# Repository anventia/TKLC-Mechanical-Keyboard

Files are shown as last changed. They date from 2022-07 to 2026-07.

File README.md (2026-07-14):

# Tenkeyless-Compact
A Tenkeyless (TKL) Mechanical Keyboard, but more compact.
- PCB custom-made in KiCAD
- Support for:
  - Standard Cherry-style hotswappable switches
  - Gateron Low Profile hotswappable switches + Kailh Choc LP Stabilizers
- 3D printed plate + case 
 




[More images here](https://photos.anv3d.net/share/XmMfmQBNBfAzoucF3x74RvwrajWIMN9iaQ0uHyBkrugpA7lCPas15zOcdVT3Yqxft6Q)

Layout (from [Keyboard Layout Editor](http://www.keyboard-layout-editor.com/))
tkl-compact (2)

Libraries used: 
- https://github.com/sszczep/kicad-libraries
- https://github.com/Kriechi/kicad-library-WeAct-RP2040-Pico

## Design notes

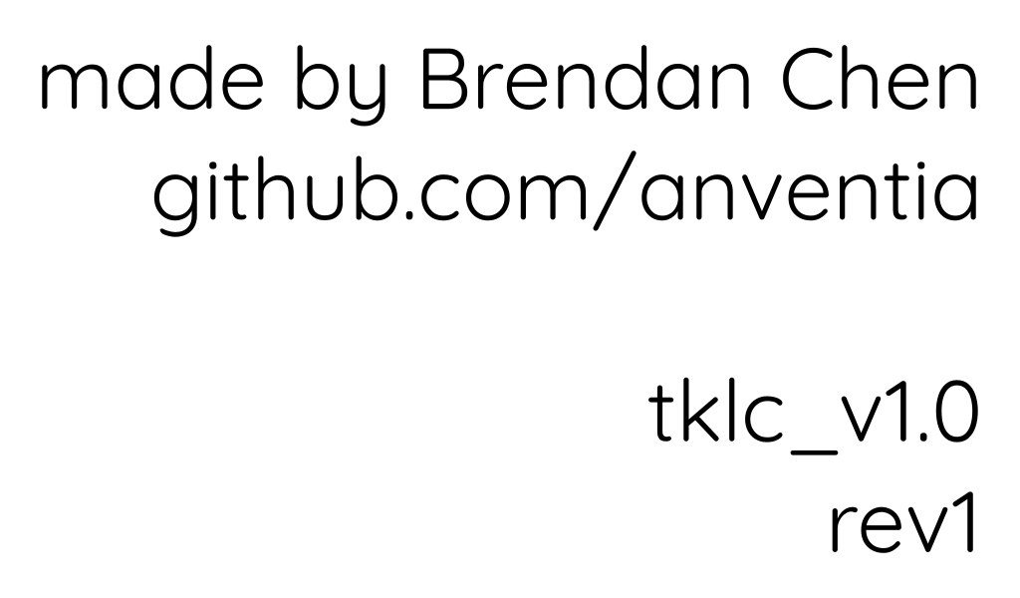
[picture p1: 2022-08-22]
TKLC_v1/resources/text.png

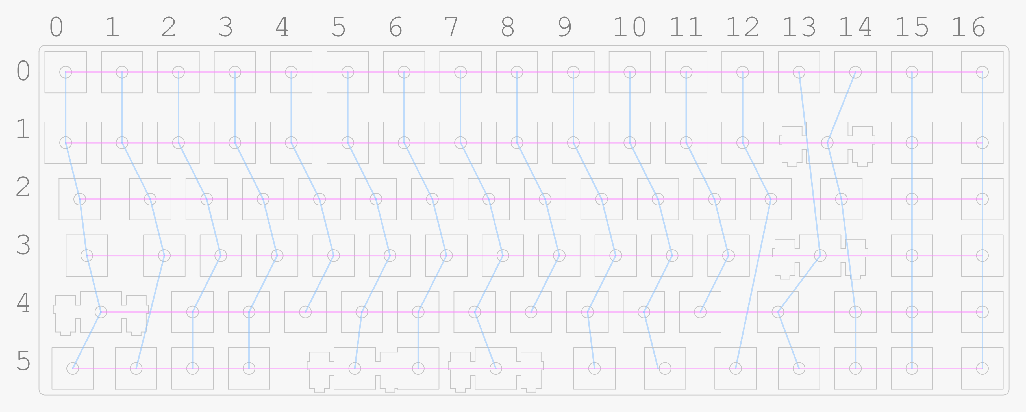
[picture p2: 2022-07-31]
TKLC_v1/resources/rows_columns_reference.png

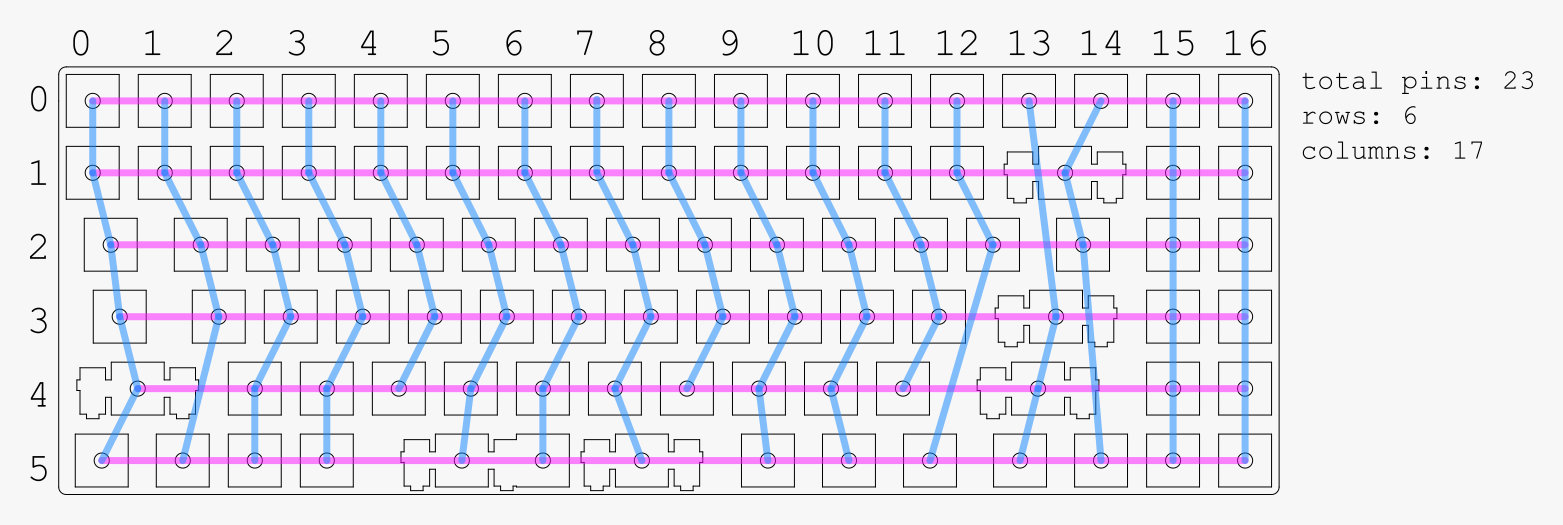
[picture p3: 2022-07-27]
TKLC_v1/resources/rows_columns.png

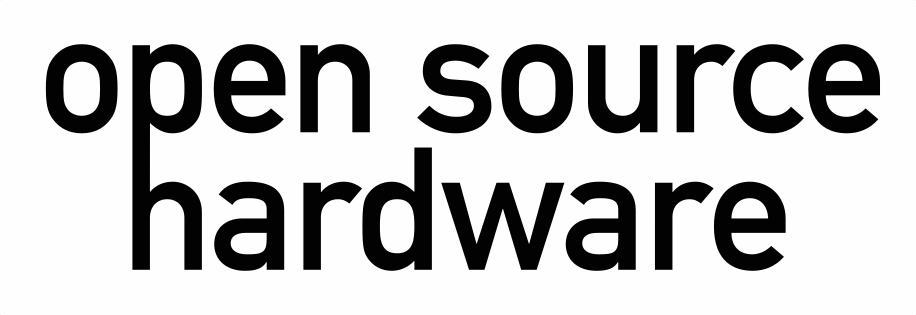
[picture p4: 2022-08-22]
TKLC_v1/resources/oshw_text.png

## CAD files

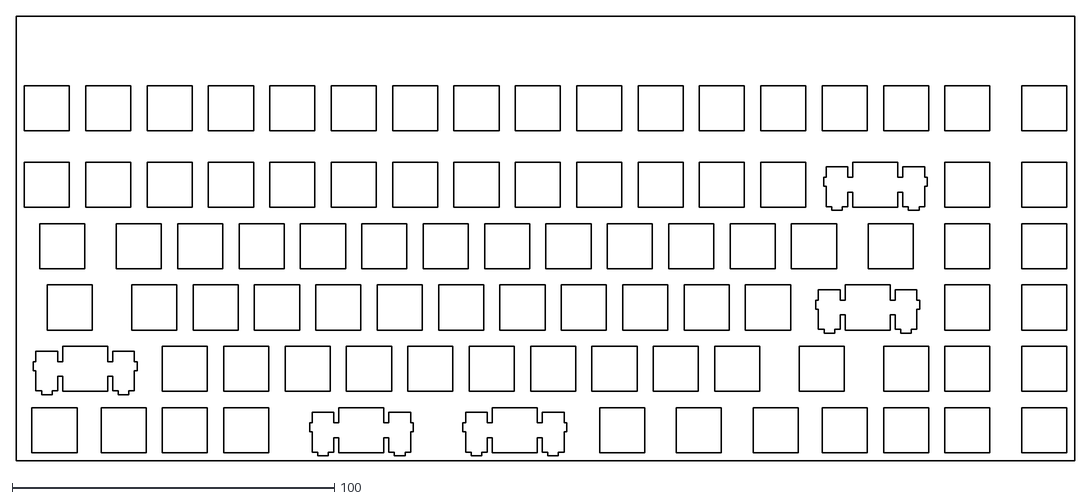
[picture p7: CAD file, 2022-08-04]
TKLC_v1/resources/layout-updated.dxf
328.6 x 138.1

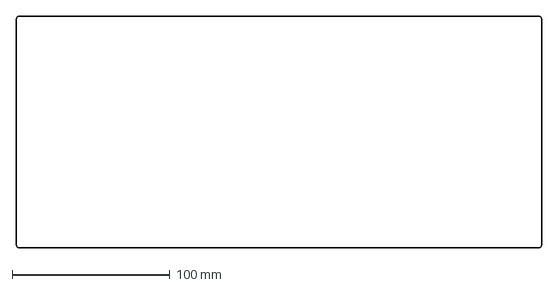
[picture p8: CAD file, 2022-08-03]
TKLC_v1/resources/pcb_frame.dxf
332.6 x 146.9 mm

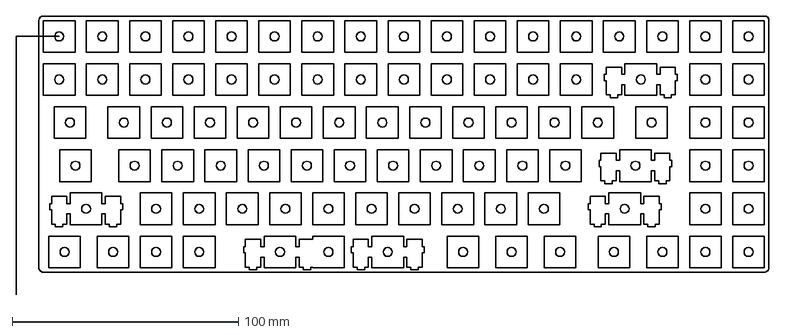
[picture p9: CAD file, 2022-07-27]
TKLC_v1/resources/switch_alignment.dxf
332.9 x 123.3 mm

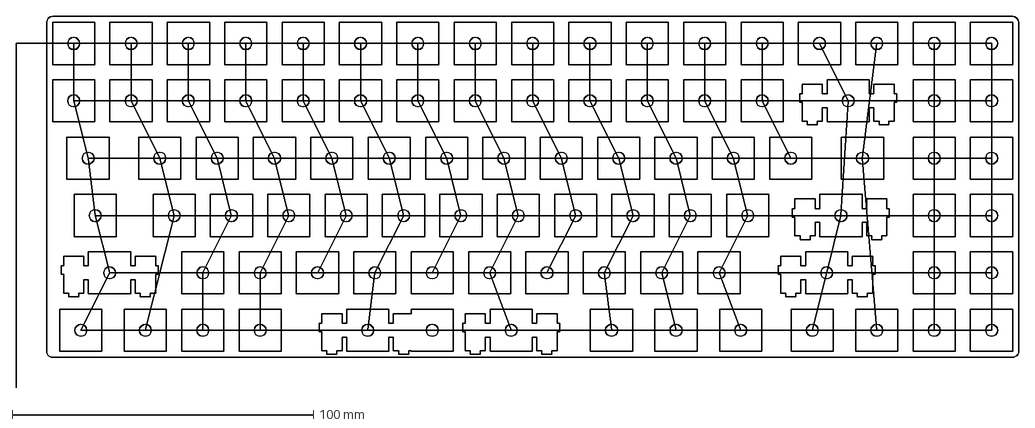
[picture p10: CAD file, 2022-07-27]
TKLC_v1/resources/rows_columns.dxf
332.9 x 123.3 mm

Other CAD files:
TKLC_v1/resources/test.dxf

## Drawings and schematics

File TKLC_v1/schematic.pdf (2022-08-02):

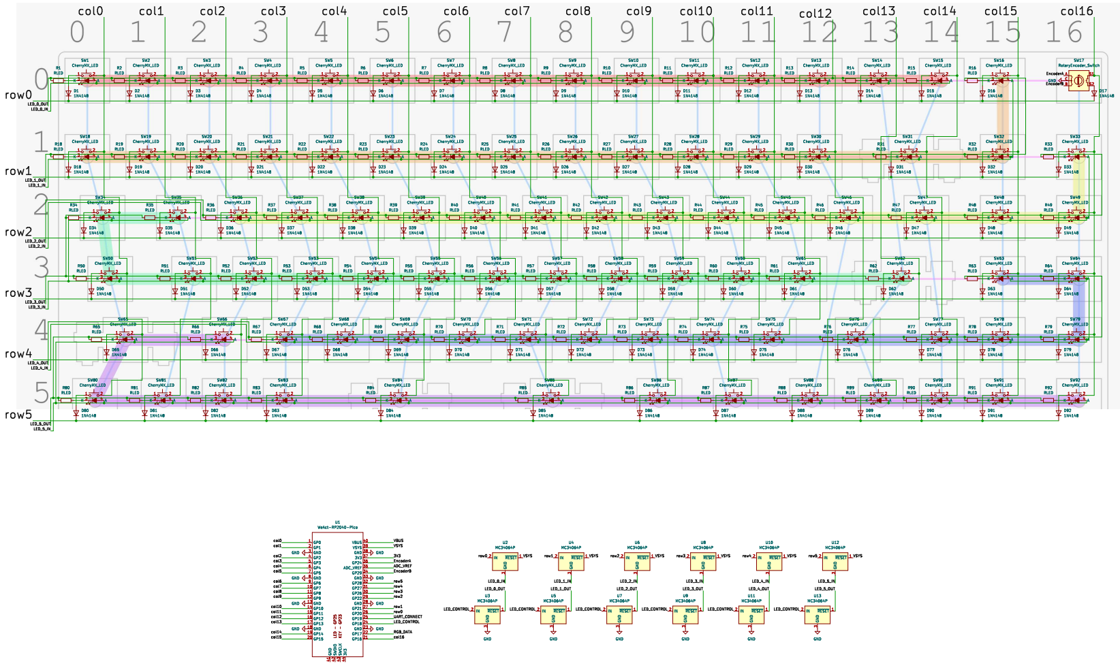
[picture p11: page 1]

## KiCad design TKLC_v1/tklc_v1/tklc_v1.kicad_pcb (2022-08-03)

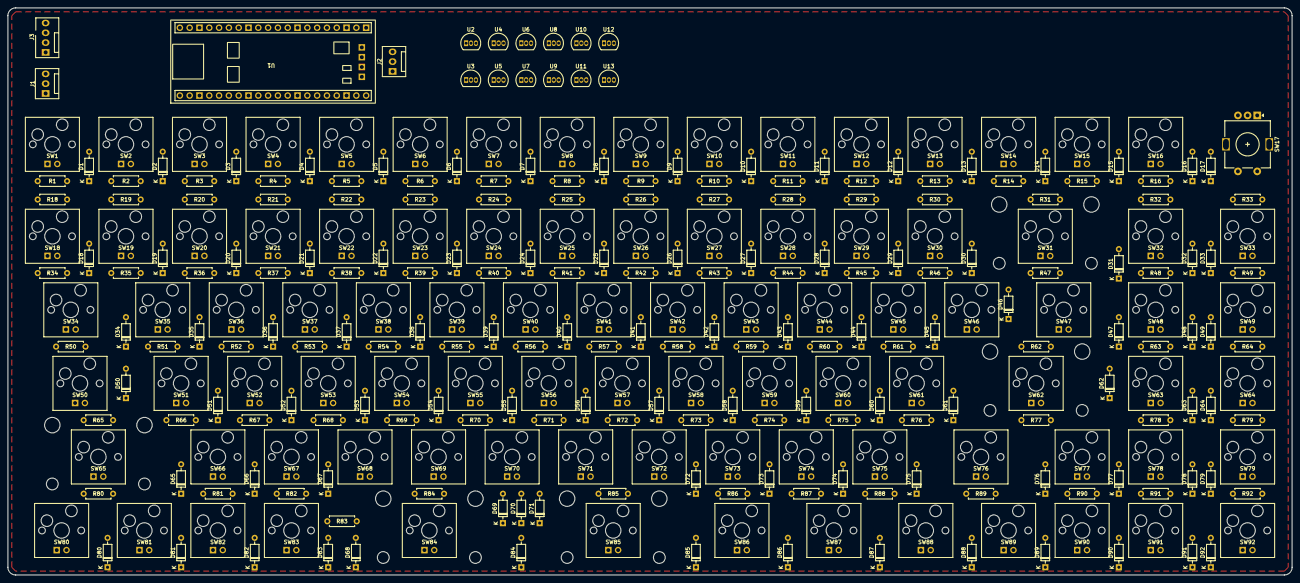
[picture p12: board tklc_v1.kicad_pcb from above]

Board: 2 copper layers, 332.6 x 146.9 mm, 291 parts (0 on the bottom side), 227 nets, no tracks yet.

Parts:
D1, D2, D3, D4, D5, D6, D7, D8, D9, D10, D11, D12, D13, D14, D15, D16, D17, D18, D19, D20, D21, D22, D23, D24, D25, D26, D27, D28, D29, D30, D31, D32, D33, D34, D35, D36, D37, D38, D39, D40, D41, D42, D43, D44, D45, D46, D47, D48, D49, D50, D51, D52, D53, D54, D55, D56, D57, D58, D59, D60, D61, D62, D63, D64, D65, D66, D67, D68, D69, D70, D71, D72, D73, D74, D75, D76, D77, D78, D79, D80, D81, D82, D83, D84, D85, D86, D87, D88, D89, D90, D91, D92: 1N4148; D_DO-35_SOD27_P7.62mm_Horizontal
J1: UART breakout for extension board; FanPinHeader_1x03_P2.54mm_Vertical
J2: RGB Strip breakout; FanPinHeader_1x03_P2.54mm_Vertical
J3: Encoder breakout; FanPinHeader_1x04_P2.54mm_Vertical
R1, R2, R3, R4, R5, R6, R7, R8, R9, R10, R11, R12, R13, R14, R15, R16, R18, R19, R20, R21, R22, R23, R24, R25, R26, R27, R28, R29, R30, R31, R32, R33, R34, R35, R36, R37, R38, R39, R40, R41, R42, R43, R44, R45, R46, R47, R48, R49, R50, R51, R52, R53, R54, R55, R56, R57, R58, R59, R60, R61, R62, R63, R64, R65, R66, R67, R68, R69, R70, R71, R72, R73, R74, R75, R76, R77, R78, R79, R80, R81, R82, R83, R84, R85, R86, R87, R88, R89, R90, R91, R92: RLED; R_Axial_DIN0207_L6.3mEDIT_m_D2.5mm_P7.62mm_Horizontal
SW1, SW2, SW3, SW4, SW5, SW6, SW7, SW8, SW9, SW10, SW11, SW12, SW13, SW14, SW15, SW16, SW18, SW19, SW20, SW21, SW22, SW23, SW24, SW25, SW26, SW27, SW28, SW29, SW30, SW32, SW33, SW35, SW36, SW37, SW38, SW39, SW40, SW41, SW42, SW43, SW44, SW45, SW46, SW48, SW49, SW51, SW52, SW53, SW54, SW55, SW56, SW57, SW58, SW59, SW60, SW61, SW63, SW64, SW66, SW67, SW68, SW69, SW70, SW71, SW72, SW73, SW74, SW75, SW77, SW78, SW79, SW81, SW82, SW83, SW89, SW90, SW91, SW92: CherryMX_LED; CherryMX_1.00u_PCB_KailhSocket_LED
SW17: RotaryEncoder_Switch; EDIT_RotaryEncoder_Alps_EC11E-Switch_Vertical_H20mm
SW31: CherryMX_LED; CherryMX_2.00u_PCB_KailhSocket_StabWireTop_LED
SW34, SW47: CherryMX_LED; CherryMX_1.50u_PCB_KailhSocket_LED
SW50, SW76: CherryMX_LED; CherryMX_1.75u_PCB_KailhSocket_LED
SW62, SW65, SW85: CherryMX_LED; CherryMX_2.25u_PCB_KailhSocket_StabWireTop_LED
SW80, SW86, SW87, SW88: CherryMX_LED; CherryMX_1.25u_PCB_KailhSocket_LED
SW84: CherryMX_LED; CherryMX_2.75u_PCB_KailhSocket_StabWireTop_LED
U1: WeAct-RP2040-Pico
U2, U3, U4, U5, U6, U7, U8, U9, U10, U11, U12, U13: MC34064P; TO-92L_Inline

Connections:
/3V3: J1.3, U1.37 (3V3)
/EncoderA: J3.1, SW17.A, U1.36 (GP24)
/EncoderB: J3.2, SW17.B, U1.34 (GP29)
/LED_0_IN: SW1.4 (A), SW2.4 (A), SW3.4 (A), SW4.4 (A), SW5.4 (A), SW6.4 (A), SW7.4 (A), SW8.4 (A), SW9.4 (A), SW10.4 (A), SW11.4 (A), SW12.4 (A), SW13.4 (A), SW14.4 (A), SW15.4 (A), U2.3 (GND)
/LED_0_OUT: R1.1, R2.1, R3.1, R4.1, R5.1, R6.1, R7.1, R8.1, R9.1, R10.1, R11.1, R12.1, R13.1, R14.1, R15.1, U1.16 (GP12), U3.1 (~RESET)
/LED_1_IN: SW16.4 (A), SW18.4 (A), SW19.4 (A), SW20.4 (A), SW21.4 (A), SW22.4 (A), SW23.4 (A), SW24.4 (A), SW25.4 (A), SW26.4 (A), SW27.4 (A), SW28.4 (A), SW29.4 (A), SW30.4 (A), SW31.4 (A), SW32.4 (A), U4.3 (GND)
/LED_1_OUT: R16.1, R18.1, R19.1, R20.1, R21.1, R22.1, R23.1, R24.1, R25.1, R26.1, R27.1, R28.1, R29.1, R30.1, R31.1, R32.1, U5.1 (~RESET)
/LED_2_IN: SW33.4 (A), SW36.4 (A), SW37.4 (A), SW38.4 (A), SW39.4 (A), SW40.4 (A), SW41.4 (A), SW42.4 (A), SW43.4 (A), SW44.4 (A), SW45.4 (A), SW46.4 (A), SW47.4 (A), SW48.4 (A), SW49.4 (A), U6.3 (GND)
/LED_2_OUT: R33.1, R36.1, R37.1, R38.1, R39.1, R40.1, R41.1, R42.1, R43.1, R44.1, R45.1, R46.1, R47.1, R48.1, R49.1, U7.1 (~RESET)
/LED_3_IN: SW34.4 (A), SW35.4 (A), SW50.4 (A), SW51.4 (A), SW52.4 (A), SW53.4 (A), SW54.4 (A), SW55.4 (A), SW56.4 (A), SW57.4 (A), SW58.4 (A), SW59.4 (A), SW60.4 (A), SW61.4 (A), SW62.4 (A), U8.3 (GND)
/LED_3_OUT: R34.1, R35.1, R50.1, R51.1, R52.1, R53.1, R54.1, R55.1, R56.1, R57.1, R58.1, R59.1, R60.1, R61.1, R62.1, U9.1 (~RESET)
/LED_4_IN: SW63.4 (A), SW64.4 (A), SW67.4 (A), SW68.4 (A), SW69.4 (A), SW70.4 (A), SW71.4 (A), SW72.4 (A), SW73.4 (A), SW74.4 (A), SW75.4 (A), SW76.4 (A), SW77.4 (A), SW78.4 (A), SW79.4 (A), U10.3 (GND)
/LED_4_OUT: R63.1, R64.1, R67.1, R68.1, R69.1, R70.1, R71.1, R72.1, R73.1, R74.1, R75.1, R76.1, R77.1, R78.1, R79.1, U11.1 (~RESET)
/LED_5_IN: SW65.4 (A), SW66.4 (A), SW80.4 (A), SW81.4 (A), SW82.4 (A), SW83.4 (A), SW84.4 (A), SW85.4 (A), SW86.4 (A), SW87.4 (A), SW88.4 (A), SW89.4 (A), SW90.4 (A), SW91.4 (A), SW92.4 (A), U12.3 (GND)
/LED_5_OUT: R65.1, R66.1, R80.1, R81.1, R82.1, R83.1, R84.1, R85.1, R86.1, R87.1, R88.1, R89.1, R90.1, R91.1, R92.1, U13.1 (~RESET)
/LED_CONTROL: U1.24 (GP18), U3.2 (IN), U5.2 (IN), U7.2 (IN), U9.2 (IN), U11.2 (IN), U13.2 (IN)
/RGB_DATA: J2.3, U1.22 (GP17)
/UART_CONNECT: J1.2, U1.25 (GP19)
/VBUS: J2.2, U1.40 (VBUS)
/VSYS: U1.39 (VSYS), U2.1 (~RESET), U4.1 (~RESET), U6.1 (~RESET), U8.1 (~RESET), U10.1 (~RESET), U12.1 (~RESET)
/col0: SW1.2, SW18.2, SW34.2, SW50.2, SW65.2, SW80.2, U1.1 (GP0)
/col1: SW2.2, SW19.2, SW35.2, SW51.2, SW81.2, U1.2 (GP1)
/col2: SW3.2, SW20.2, SW36.2, SW52.2, SW66.2, SW82.2, U1.4 (GP2)
/col3: SW4.2, SW21.2, SW37.2, SW53.2, SW67.2, SW83.2, U1.5 (GP3)
/col4: SW5.2, SW22.2, SW38.2, SW54.2, SW68.2, U1.6 (GP4)
/col5: SW6.2, SW23.2, SW39.2, SW55.2, SW69.2, SW84.2, U1.7 (GP5)
/col6: SW7.2, SW24.2, SW40.2, SW56.2, SW70.2, U1.9 (GP6)
/col7: SW8.2, SW25.2, SW41.2, SW57.2, SW71.2, SW85.2, U1.10 (GP7)
/col8: SW9.2, SW26.2, SW42.2, SW58.2, SW72.2, U1.11 (GP8)
/col9: SW10.2, SW27.2, SW43.2, SW59.2, SW73.2, SW86.2, U1.12 (GP9)
/col10: SW11.2, SW28.2, SW44.2, SW60.2, SW74.2, SW87.2, U1.14 (GP10)
/col11: SW12.2, SW29.2, SW45.2, SW61.2, SW75.2, U1.15 (GP11)
/col13: SW14.2, SW62.2, SW76.2, SW89.2, U1.17 (GP13)
/col14: SW15.2, SW31.2, SW47.2, SW77.2, SW90.2, U1.19 (GP14)
/col15: SW16.2, SW32.2, SW48.2, SW63.2, SW78.2, SW91.2, U1.20 (GP15)
/col16: J3.3, SW17.S1, SW33.2, SW49.2, SW64.2, SW79.2, SW92.2, U1.21 (GP16)
/row0: D1.1 (K), D2.1 (K), D3.1 (K), D4.1 (K), D5.1 (K), D6.1 (K), D7.1 (K), D8.1 (K), D9.1 (K), D10.1 (K), D11.1 (K), D12.1 (K), D13.1 (K), D14.1 (K), D15.1 (K), D16.1 (K), D17.1 (K), J3.4, U1.26 (GP20), U2.2 (IN)
/row1: D18.1 (K), D19.1 (K), D20.1 (K), D21.1 (K), D22.1 (K), D23.1 (K), D24.1 (K), D25.1 (K), D26.1 (K), D27.1 (K), D28.1 (K), D29.1 (K), D30.1 (K), D31.1 (K), D32.1 (K), D33.1 (K), U1.27 (GP21), U4.2 (IN)
/row2: D34.1 (K), D35.1 (K), D36.1 (K), D37.1 (K), D38.1 (K), D39.1 (K), D40.1 (K), D41.1 (K), D42.1 (K), D43.1 (K), D44.1 (K), D45.1 (K), D46.1 (K), D47.1 (K), D48.1 (K), D49.1 (K), U1.29 (GP22), U6.2 (IN)
/row3: D50.1 (K), D51.1 (K), D52.1 (K), D53.1 (K), D54.1 (K), D55.1 (K), D56.1 (K), D57.1 (K), D58.1 (K), D59.1 (K), D60.1 (K), D61.1 (K), D62.1 (K), D63.1 (K), D64.1 (K), U1.30 (GP26), U8.2 (IN)
/row4: D65.1 (K), D66.1 (K), D67.1 (K), D68.1 (K), D69.1 (K), D70.1 (K), D71.1 (K), D72.1 (K), D73.1 (K), D74.1 (K), D75.1 (K), D76.1 (K), D77.1 (K), D78.1 (K), D79.1 (K), U1.31 (GP27), U10.2 (IN)
/row5: D80.1 (K), D81.1 (K), D82.1 (K), D83.1 (K), D84.1 (K), D85.1 (K), D86.1 (K), D87.1 (K), D88.1 (K), D89.1 (K), D90.1 (K), D91.1 (K), D92.1 (K), U1.32 (GP28), U12.2 (IN)
GND: J1.1, J2.1, SW17.C, U1.3 (GND), U1.8 (GND), U1.13 (GND), U1.18 (GND), U1.23 (GND), U1.28 (GND), U1.33 (GND), U1.38 (GND), U3.3 (GND), U5.3 (GND), U7.3 (GND), U9.3 (GND), U11.3 (GND), U13.3 (GND)
unnamed: D1.2 (A), SW1.1
unnamed: D2.2 (A), SW2.1
unnamed: D3.2 (A), SW3.1
unnamed: D4.2 (A), SW4.1
unnamed: D5.2 (A), SW5.1
unnamed: D6.2 (A), SW6.1
unnamed: D7.2 (A), SW7.1
unnamed: D8.2 (A), SW8.1
unnamed: D9.2 (A), SW9.1
unnamed: D10.2 (A), SW10.1
unnamed: D11.2 (A), SW11.1
unnamed: D12.2 (A), SW12.1
unnamed: D13.2 (A), SW13.1
unnamed: D14.2 (A), SW14.1
unnamed: D15.2 (A), SW15.1
unnamed: D16.2 (A), SW16.1
unnamed: D17.2 (A), SW17.S2
unnamed: D18.2 (A), SW18.1
unnamed: D19.2 (A), SW19.1
unnamed: D20.2 (A), SW20.1
unnamed: D21.2 (A), SW21.1
unnamed: D22.2 (A), SW22.1
unnamed: D23.2 (A), SW23.1
unnamed: D24.2 (A), SW24.1
unnamed: D25.2 (A), SW25.1
unnamed: D26.2 (A), SW26.1
unnamed: D27.2 (A), SW27.1
unnamed: D28.2 (A), SW28.1
unnamed: D29.2 (A), SW29.1
unnamed: D30.2 (A), SW30.1
unnamed: D31.2 (A), SW31.1
unnamed: D32.2 (A), SW32.1
unnamed: D33.2 (A), SW33.1
unnamed: D34.2 (A), SW34.1
unnamed: D35.2 (A), SW35.1
unnamed: D36.2 (A), SW36.1
unnamed: D37.2 (A), SW37.1
unnamed: D38.2 (A), SW38.1
unnamed: D39.2 (A), SW39.1
unnamed: D40.2 (A), SW40.1
unnamed: D41.2 (A), SW41.1
unnamed: D42.2 (A), SW42.1
unnamed: D43.2 (A), SW43.1
unnamed: D44.2 (A), SW44.1
unnamed: D45.2 (A), SW45.1
unnamed: D46.2 (A), SW46.1
unnamed: D47.2 (A), SW47.1
unnamed: D48.2 (A), SW48.1
unnamed: D49.2 (A), SW49.1
unnamed: D50.2 (A), SW50.1
unnamed: D51.2 (A), SW51.1
unnamed: D52.2 (A), SW52.1
unnamed: D53.2 (A), SW53.1
unnamed: D54.2 (A), SW54.1
unnamed: D55.2 (A), SW55.1
unnamed: D56.2 (A), SW56.1
unnamed: D57.2 (A), SW57.1
unnamed: D58.2 (A), SW58.1
unnamed: D59.2 (A), SW59.1
unnamed: D60.2 (A), SW60.1
unnamed: D61.2 (A), SW61.1
unnamed: D62.2 (A), SW62.1
unnamed: D63.2 (A), SW63.1
unnamed: D64.2 (A), SW64.1
unnamed: D65.2 (A), SW65.1
unnamed: D66.2 (A), SW66.1
unnamed: D67.2 (A), SW67.1
unnamed: D68.2 (A), SW68.1
unnamed: D69.2 (A), SW69.1
unnamed: D70.2 (A), SW70.1
unnamed: D71.2 (A), SW71.1
unnamed: D72.2 (A), SW72.1
unnamed: D73.2 (A), SW73.1
unnamed: D74.2 (A), SW74.1
unnamed: D75.2 (A), SW75.1
unnamed: D76.2 (A), SW76.1
unnamed: D77.2 (A), SW77.1
unnamed: D78.2 (A), SW78.1
unnamed: D79.2 (A), SW79.1
unnamed: D80.2 (A), SW80.1
unnamed: D81.2 (A), SW81.1
unnamed: D82.2 (A), SW82.1
unnamed: D83.2 (A), SW83.1
unnamed: D84.2 (A), SW84.1
unnamed: D85.2 (A), SW85.1
unnamed: D86.2 (A), SW86.1
unnamed: D87.2 (A), SW87.1
unnamed: D88.2 (A), SW88.1
unnamed: D89.2 (A), SW89.1
unnamed: D90.2 (A), SW90.1
unnamed: D91.2 (A), SW91.1
unnamed: D92.2 (A), SW92.1
unnamed: R1.2, SW1.3 (K)
unnamed: R2.2, SW2.3 (K)
unnamed: R3.2, SW3.3 (K)
unnamed: R4.2, SW4.3 (K)
unnamed: R5.2, SW5.3 (K)
unnamed: R6.2, SW6.3 (K)
unnamed: R7.2, SW7.3 (K)
unnamed: R8.2, SW8.3 (K)
unnamed: R9.2, SW9.3 (K)
unnamed: R10.2, SW10.3 (K)
unnamed: R11.2, SW11.3 (K)
unnamed: R12.2, SW12.3 (K)
unnamed: R13.2, SW13.3 (K)
unnamed: R14.2, SW14.3 (K)
unnamed: R15.2, SW15.3 (K)
unnamed: R16.2, SW16.3 (K)
unnamed: R18.2, SW18.3 (K)
unnamed: R19.2, SW19.3 (K)
unnamed: R20.2, SW20.3 (K)
unnamed: R21.2, SW21.3 (K)
unnamed: R22.2, SW22.3 (K)
unnamed: R23.2, SW23.3 (K)
unnamed: R24.2, SW24.3 (K)
unnamed: R25.2, SW25.3 (K)
unnamed: R26.2, SW26.3 (K)
unnamed: R27.2, SW27.3 (K)
unnamed: R28.2, SW28.3 (K)
unnamed: R29.2, SW29.3 (K)
unnamed: R30.2, SW30.3 (K)
unnamed: R31.2, SW31.3 (K)
unnamed: R32.2, SW32.3 (K)
unnamed: R33.2, SW33.3 (K)
unnamed: R34.2, SW34.3 (K)
unnamed: R35.2, SW35.3 (K)
unnamed: R36.2, SW36.3 (K)
unnamed: R37.2, SW37.3 (K)
unnamed: R38.2, SW38.3 (K)
unnamed: R39.2, SW39.3 (K)
unnamed: R40.2, SW40.3 (K)
unnamed: R41.2, SW41.3 (K)
unnamed: R42.2, SW42.3 (K)
unnamed: R43.2, SW43.3 (K)
unnamed: R44.2, SW44.3 (K)
unnamed: R45.2, SW45.3 (K)
unnamed: R46.2, SW46.3 (K)
unnamed: R47.2, SW47.3 (K)
unnamed: R48.2, SW48.3 (K)
unnamed: R49.2, SW49.3 (K)
unnamed: R50.2, SW50.3 (K)
unnamed: R51.2, SW51.3 (K)
unnamed: R52.2, SW52.3 (K)
unnamed: R53.2, SW53.3 (K)
unnamed: R54.2, SW54.3 (K)
unnamed: R55.2, SW55.3 (K)
unnamed: R56.2, SW56.3 (K)
unnamed: R57.2, SW57.3 (K)
unnamed: R58.2, SW58.3 (K)
unnamed: R59.2, SW59.3 (K)
unnamed: R60.2, SW60.3 (K)
unnamed: R61.2, SW61.3 (K)
unnamed: R62.2, SW62.3 (K)
unnamed: R63.2, SW63.3 (K)
unnamed: R64.2, SW64.3 (K)
unnamed: R65.2, SW65.3 (K)
unnamed: R66.2, SW66.3 (K)
unnamed: R67.2, SW67.3 (K)
unnamed: R68.2, SW68.3 (K)
unnamed: R69.2, SW69.3 (K)
unnamed: R70.2, SW70.3 (K)
unnamed: R71.2, SW71.3 (K)
unnamed: R72.2, SW72.3 (K)
unnamed: R73.2, SW73.3 (K)
unnamed: R74.2, SW74.3 (K)
unnamed: R75.2, SW75.3 (K)
unnamed: R76.2, SW76.3 (K)
unnamed: R77.2, SW77.3 (K)
unnamed: R78.2, SW78.3 (K)
unnamed: R79.2, SW79.3 (K)
unnamed: R80.2, SW80.3 (K)
unnamed: R81.2, SW81.3 (K)
unnamed: R82.2, SW82.3 (K)
unnamed: R83.2, SW83.3 (K)
unnamed: R84.2, SW84.3 (K)
unnamed: R85.2, SW85.3 (K)
unnamed: R86.2, SW86.3 (K)
unnamed: R87.2, SW87.3 (K)
unnamed: R88.2, SW88.3 (K)
unnamed: R89.2, SW89.3 (K)
unnamed: R90.2, SW90.3 (K)
unnamed: R91.2, SW91.3 (K)
unnamed: R92.2, SW92.3 (K)
unnamed: SW13.2, SW30.2, SW46.2, SW88.2

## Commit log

2022-08-03 Finished laying out PCB
    [pcb_frame.dxf, tklc_v1.kicad_pcb, tklc_v1.kicad_sch]
2022-08-04 Changed resistor layout
2022-08-04 Rows and columns finished wiring
    Removed LED wiring, may switch to RGB
2022-08-05 Added SK6812 LEDs to schematic
    [tklc_v1.kicad_sch]
2022-08-05 Restructure versions
    [tklc_v1.kicad_sch]
2022-08-15 Started Low Profile ver
    [tklc_v1_rgb_LP.kicad_sch]
2022-08-18 Finished wiring LEDs and Matrix to each other
    [tklc_v1_rgb_LP.kicad_sch]
2022-08-19 renaming stuff
    [tklc_v1_rgb_LP.kicad_sch]
2022-08-19 this dir used to be called LP, but is now renamed
    [tklc_v1_rgb.kicad_sch]
2022-08-19 Wired columns
    [tklc_v1_rgb.kicad_sch]
2022-08-20 Finished wiring everything but LED Power
    [tklc_v1_rgb.kicad_sch]
2022-08-20 FINISHED! Just need finishing touches
    need to do rotary encoder button, art, and add teardrops and rounded corners.
    [tklc_v1_rgb.kicad_sch]
2022-08-22 Finished art, added mounting holes and teardrops.
    [test.dxf]
2022-08-28 Generated Gerber files and ordered PCBs
    [tklc_v1_rgb-B_Mask.gbs, tklc_v1_rgb-B_Paste.gbp, tklc_v1_rgb-B_Silkscreen.gbo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]
2022-08-29 Fixed problem with tracks too close to edge cuts
    [tklc_v1_rgb-B_Mask.gbs, tklc_v1_rgb-B_Paste.gbp, tklc_v1_rgb-B_Silkscreen.gbo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]
